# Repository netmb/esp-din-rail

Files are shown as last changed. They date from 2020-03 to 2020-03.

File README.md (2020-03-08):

# esp-din-rail

Din-Rail-Adapter Board for ESP32-Dev-Boards. There are many Dev-Boards available - so please check out if the pin-out matches.
The adapter-board fits in an H-Tronic HUT-6C-casing. Be aware that the current version needs some trimming on the edges, so that it fits exactly into the case.
An upcoming version should fix this issue.

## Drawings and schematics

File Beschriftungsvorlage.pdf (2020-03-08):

18 19 20 21 22 23 24 25 26 27 28 29 30 31 32 33 34 35

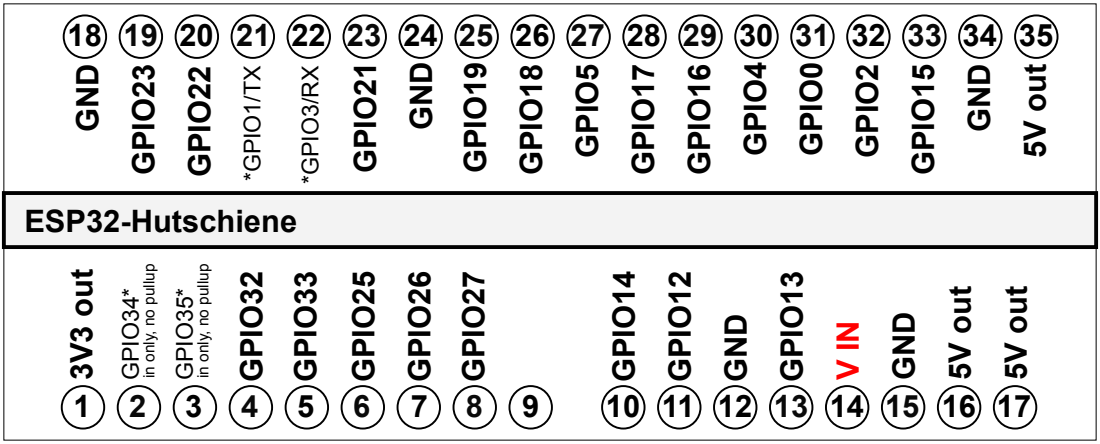
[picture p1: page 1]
10 11 12 13 14 15 16 17 GND GPIO²³ GPIO²² *GPIO¹/TX; *GPIO³/RX; GPIO²¹ GND GPIO¹⁹ GPIO¹⁸ GPIO⁵ GPIO¹⁷ GPIO¹⁶ GPIO⁴ GPIO⁰ GPIO² GPIO¹⁵ GND 5V out 3V³ out; GPIO³⁴* in only, no pullup; GPIO³⁵* in only, no pullup; GPIO³² GPIO³³ GPIO²⁵ GPIO²⁶ GPIO²⁷; GPIO¹⁴ GPIO¹² GND GPIO¹³ V IN GND 5V out; 5V out; ESP32-Hutschiene

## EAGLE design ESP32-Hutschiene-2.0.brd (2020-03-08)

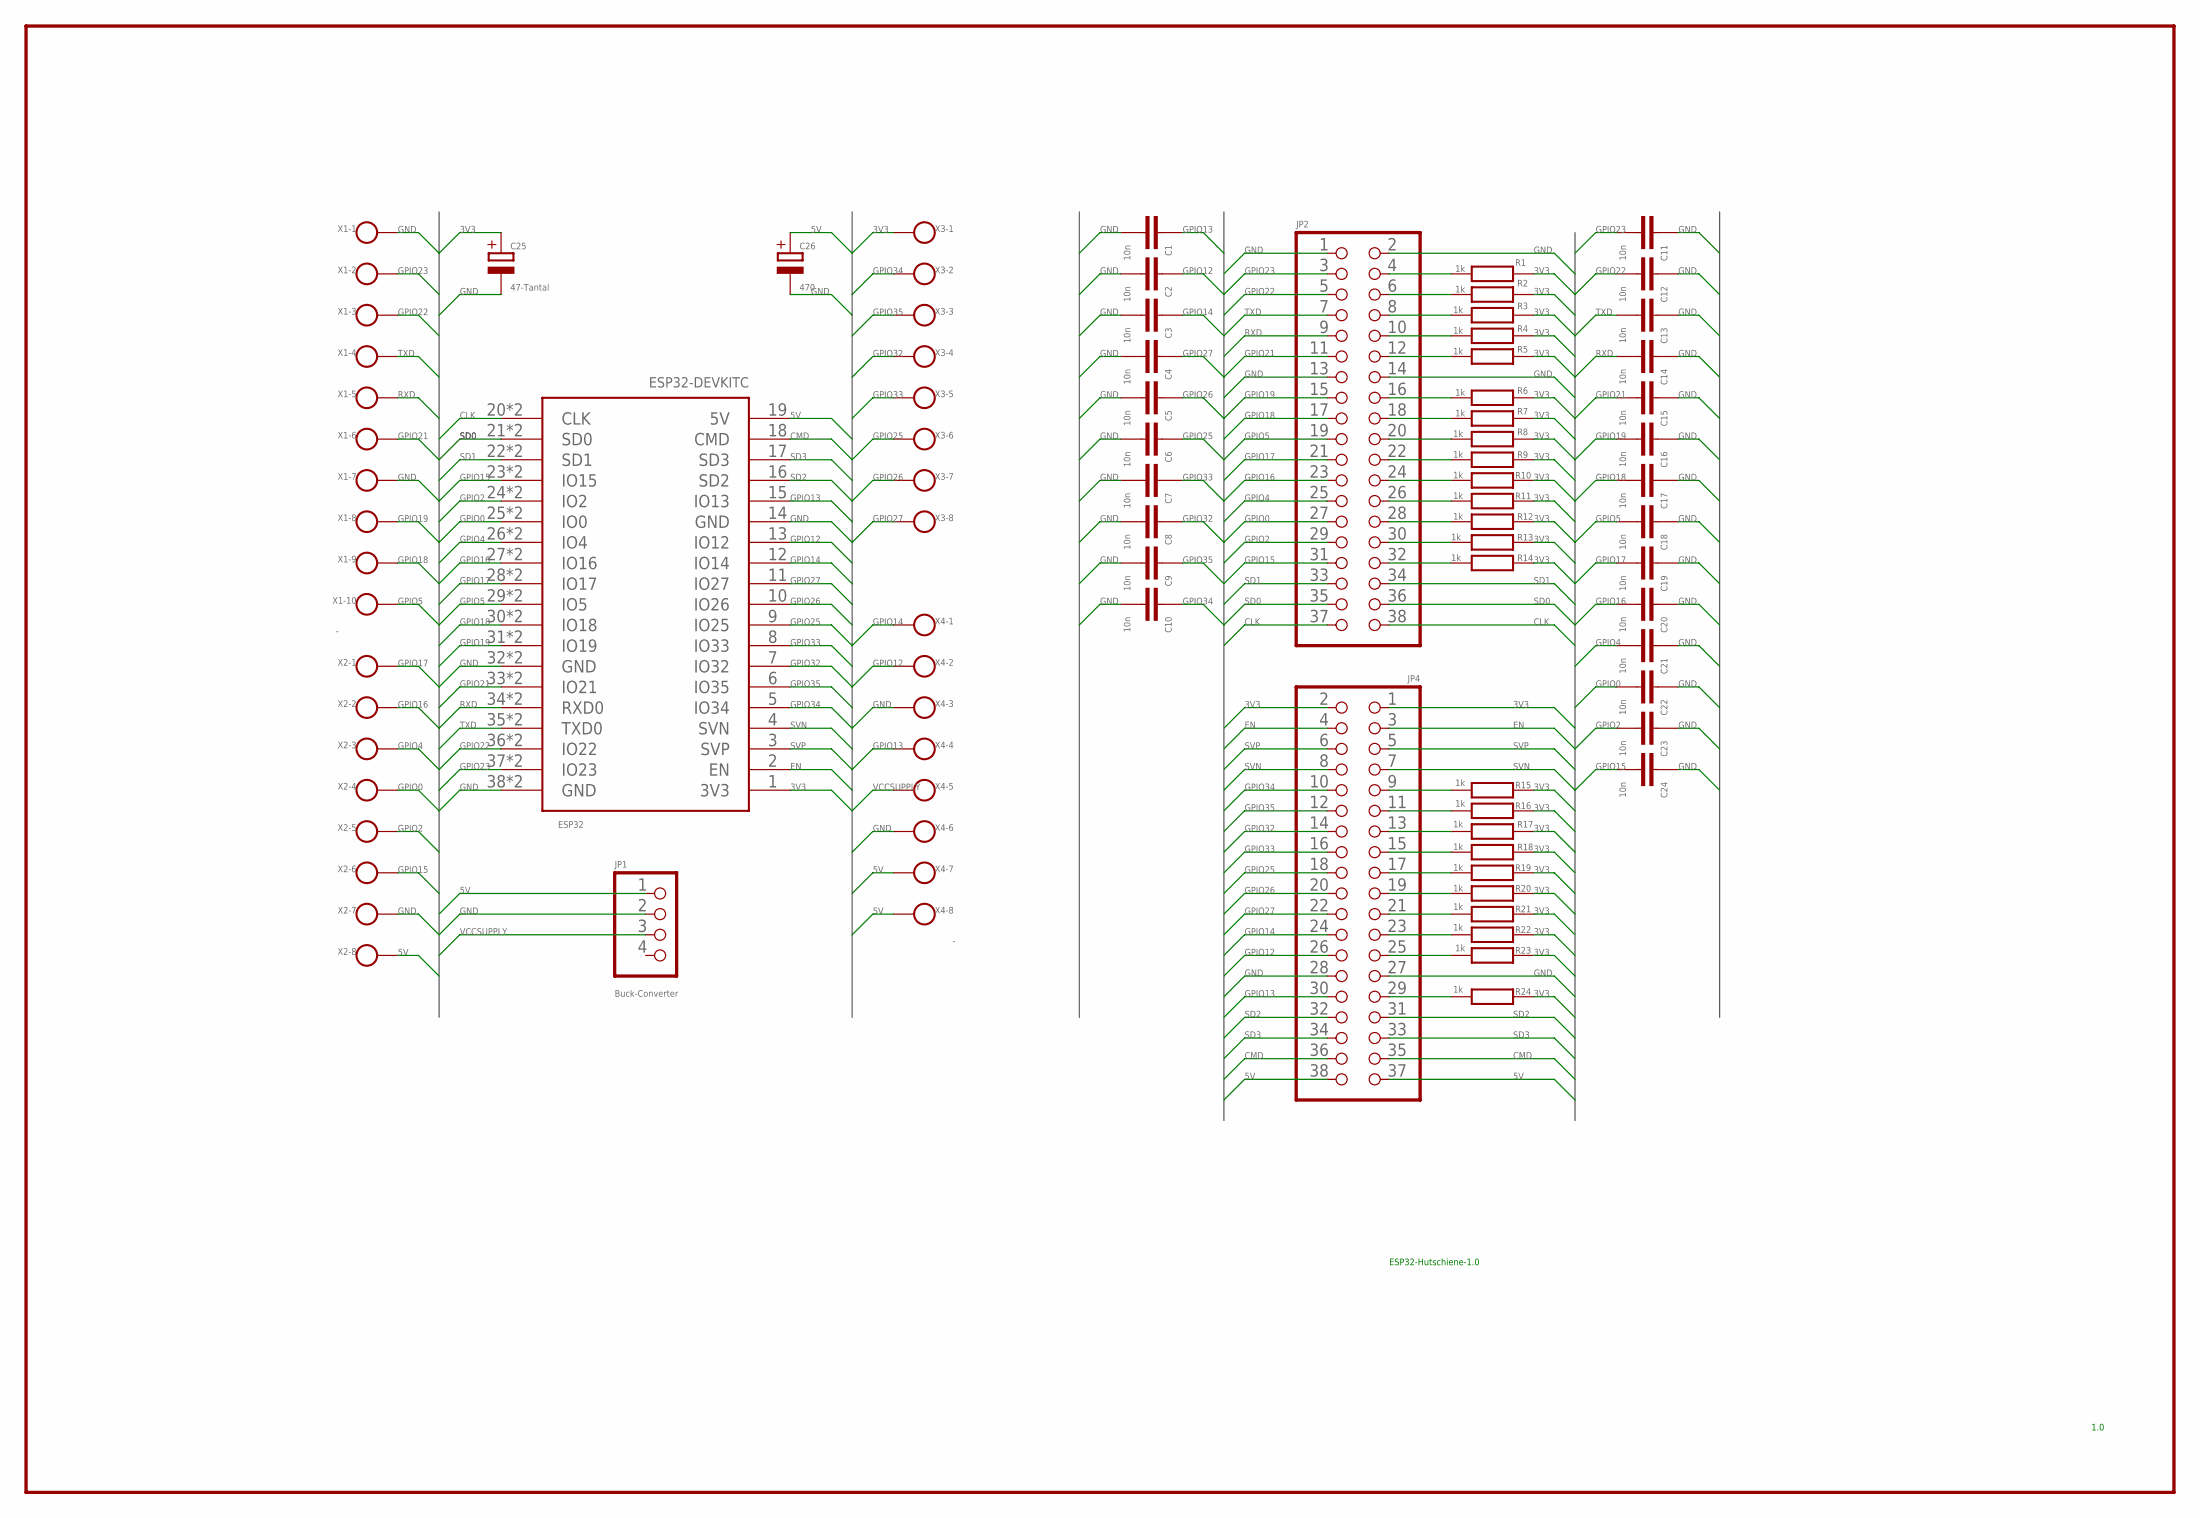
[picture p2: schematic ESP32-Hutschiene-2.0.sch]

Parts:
C1, C2, C3, C4, C5, C6, C7, C8, C9, C10, C11, C12, C13, C14, C15, C16, C17, C18, C19, C20, C21, C22, C23, C24: 10n; C0603
C25: 47-Tantal; E3,5-8
C26: 470; E3,5-8
ESP32: ESP32-DEVKITC-38P
JP1: Buck-Converter; 1X04
JP2, JP4: 2X19
R1, R2, R3, R4, R5, R6, R7, R8, R9, R10, R11, R12, R13, R14, R15, R16, R17, R18, R19, R20, R21, R22, R23, R24: 1k; R0603
X1: -; W237-10P
X2: W237-8P
X3: W237-9P
X4: -; W237-8P

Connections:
3V3: C25.+, ESP32.1 (3V3), JP4.1, JP4.2, R1.2, R2.2, R3.2, R4.2, R5.2, R6.2, R7.2, R8.2, R9.2, R10.2, R11.2, R12.2, R13.2, R14.2, R15.2, R16.2, R17.2, R18.2, R19.2, R20.2, R21.2, R22.2, R23.2, R24.2, X3.1
5V: C26.+, ESP32.19 (5V), JP1.1, JP4.37, JP4.38, X2.8, X4.7, X4.8
CLK: ESP32.20 (CLK), ESP32.57 (CLK), JP2.37, JP2.38
CMD: ESP32.18 (CMD), JP4.35, JP4.36
EN: ESP32.2 (EN), JP4.3, JP4.4
GND: C1.2, C2.2, C3.2, C4.2, C5.2, C6.2, C7.2, C8.2, C9.2, C10.2, C11.1, C12.1, C13.1, C14.1, C15.1, C16.1, C17.1, C18.1, C19.1, C20.1, C21.1, C22.1, C23.1, C24.1, C25.-, C26.-, ESP32.14 (GND), ESP32.32 (GND), ESP32.38 (GND), ESP32.39 (GND), ESP32.45 (GND), JP1.2, JP2.1, JP2.2, JP2.13, JP2.14, JP4.27, JP4.28, X1.1, X1.7, X2.7, X4.3, X4.6
GPIO0: C22.2, ESP32.25 (IO0), ESP32.52 (IO0), JP2.27, X2.4
GPIO2: C23.2, ESP32.24 (IO2), ESP32.53 (IO2), JP2.29, X2.5
GPIO4: C21.2, ESP32.26 (IO4), ESP32.51 (IO4), JP2.25, X2.3
GPIO5: C18.2, ESP32.29 (IO5), ESP32.48 (IO5), JP2.19, X1.10
GPIO12: C2.1, ESP32.13 (IO12), JP4.26, X4.2
GPIO13: C1.1, ESP32.15 (IO13), JP4.30, X4.4
GPIO14: C3.1, ESP32.12 (IO14), JP4.24, X4.1
GPIO15: C24.2, ESP32.23 (IO15), ESP32.54 (IO15), JP2.31, X2.6
GPIO16: C20.2, ESP32.27 (IO16), ESP32.50 (IO16), JP2.23, X2.2
GPIO17: C19.2, ESP32.28 (IO17), ESP32.49 (IO17), JP2.21, X2.1
GPIO18: C17.2, ESP32.30 (IO18), ESP32.47 (IO18), JP2.17, X1.9
GPIO19: C16.2, ESP32.31 (IO19), ESP32.46 (IO19), JP2.15, X1.8
GPIO21: C15.2, ESP32.33 (IO21), ESP32.44 (IO21), JP2.11, X1.6
GPIO22: C12.2, ESP32.36 (IO22), ESP32.41 (IO22), JP2.5, X1.3
GPIO23: C11.2, ESP32.37 (IO23), ESP32.40 (IO23), JP2.3, X1.2
GPIO25: C6.1, ESP32.9 (IO25), JP4.18, X3.6
GPIO26: C5.1, ESP32.10 (IO26), JP4.20, X3.7
GPIO27: C4.1, ESP32.11 (IO27), JP4.22, X3.8
GPIO32: C8.1, ESP32.7 (IO32), JP4.14, X3.4
GPIO33: C7.1, ESP32.8 (IO33), JP4.16, X3.5
GPIO34: C10.1, ESP32.5 (IO34), JP4.10, X3.2
GPIO35: C9.1, ESP32.6 (IO35), JP4.12, X3.3
unnamed: JP2.4, R1.1
unnamed: JP2.6, R2.1
unnamed: JP2.8, R3.1
unnamed: JP2.10, R4.1
unnamed: JP2.12, R5.1
unnamed: JP2.16, R6.1
unnamed: JP2.18, R7.1
unnamed: JP2.20, R8.1
unnamed: JP2.22, R9.1
unnamed: JP2.24, R10.1
unnamed: JP2.26, R11.1
unnamed: JP2.28, R12.1
unnamed: JP2.30, R13.1
unnamed: JP2.32, R14.1
unnamed: JP4.9, R15.1
unnamed: JP4.11, R16.1
unnamed: JP4.13, R17.1
unnamed: JP4.15, R18.1
unnamed: JP4.17, R19.1
unnamed: JP4.19, R20.1
unnamed: JP4.21, R21.1
unnamed: JP4.23, R22.1
unnamed: JP4.25, R23.1
unnamed: JP4.29, R24.1
RXD: C14.2, ESP32.34 (RXD0), ESP32.43 (RXD0), JP2.9, X1.5
SD0: ESP32.21 (SD0), ESP32.56 (SD0), JP2.35, JP2.36
SD1: ESP32.22 (SD1), ESP32.55 (SD1), JP2.33, JP2.34
SD2: ESP32.16 (SD2), JP4.31, JP4.32
SD3: ESP32.17 (SD3), JP4.33, JP4.34
SVN: ESP32.4 (SVN), JP4.7, JP4.8
SVP: ESP32.3 (SVP), JP4.5, JP4.6
TXD: C13.2, ESP32.35 (TXD0), ESP32.42 (TXD0), JP2.7, X1.4
VCCSUPPLY: JP1.3, X4.5

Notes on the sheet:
ESP32-Hutschiene-1.0
1.0

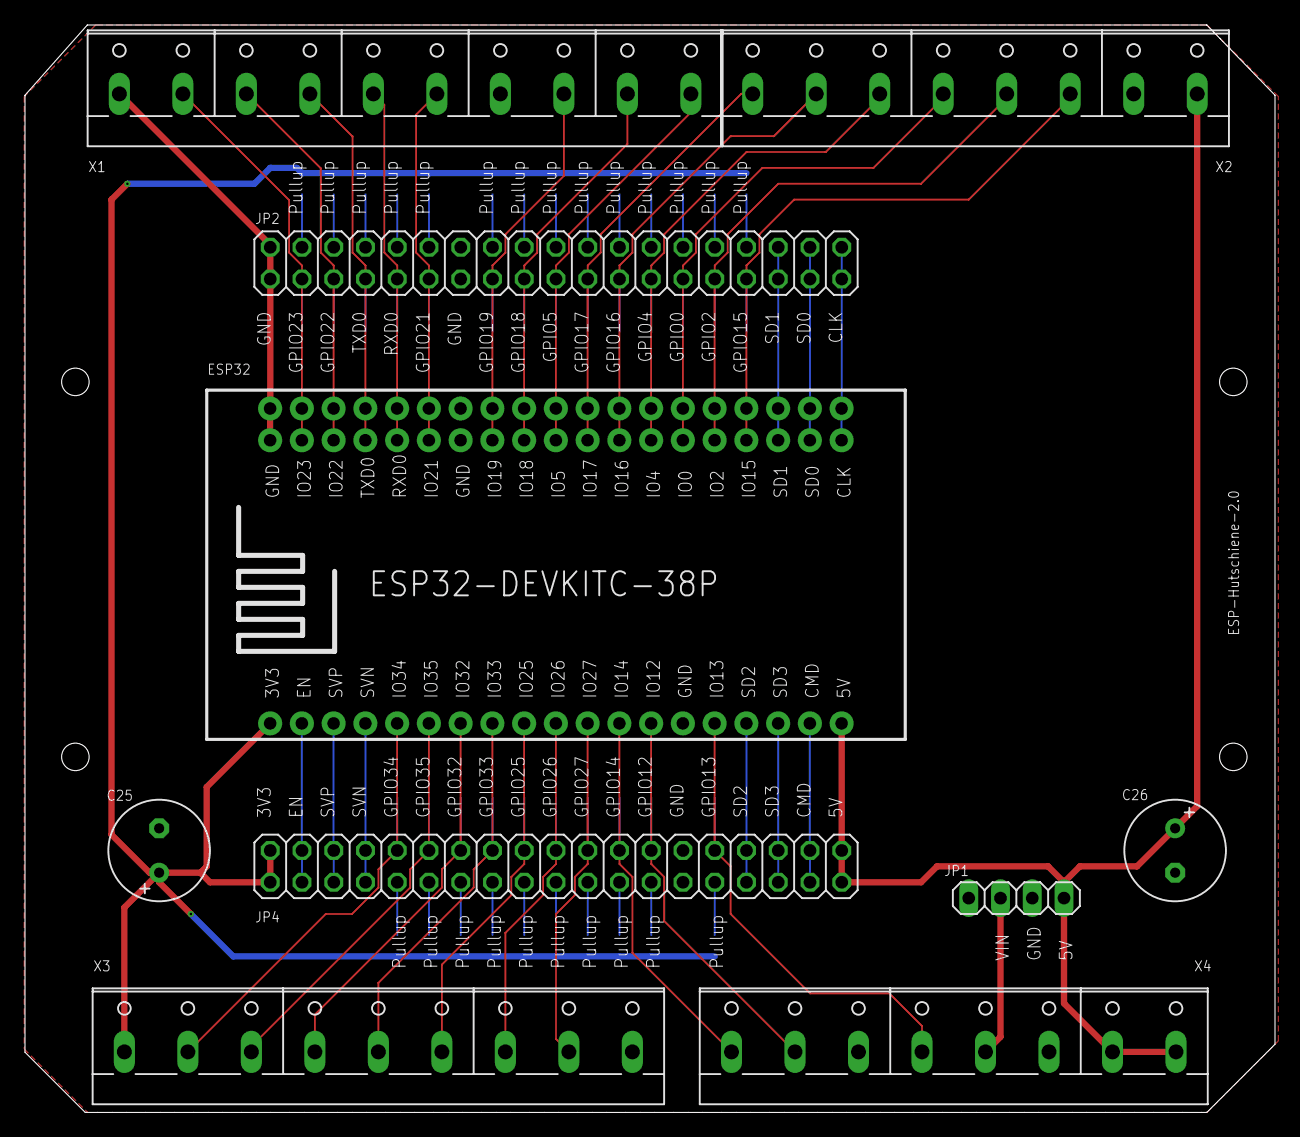
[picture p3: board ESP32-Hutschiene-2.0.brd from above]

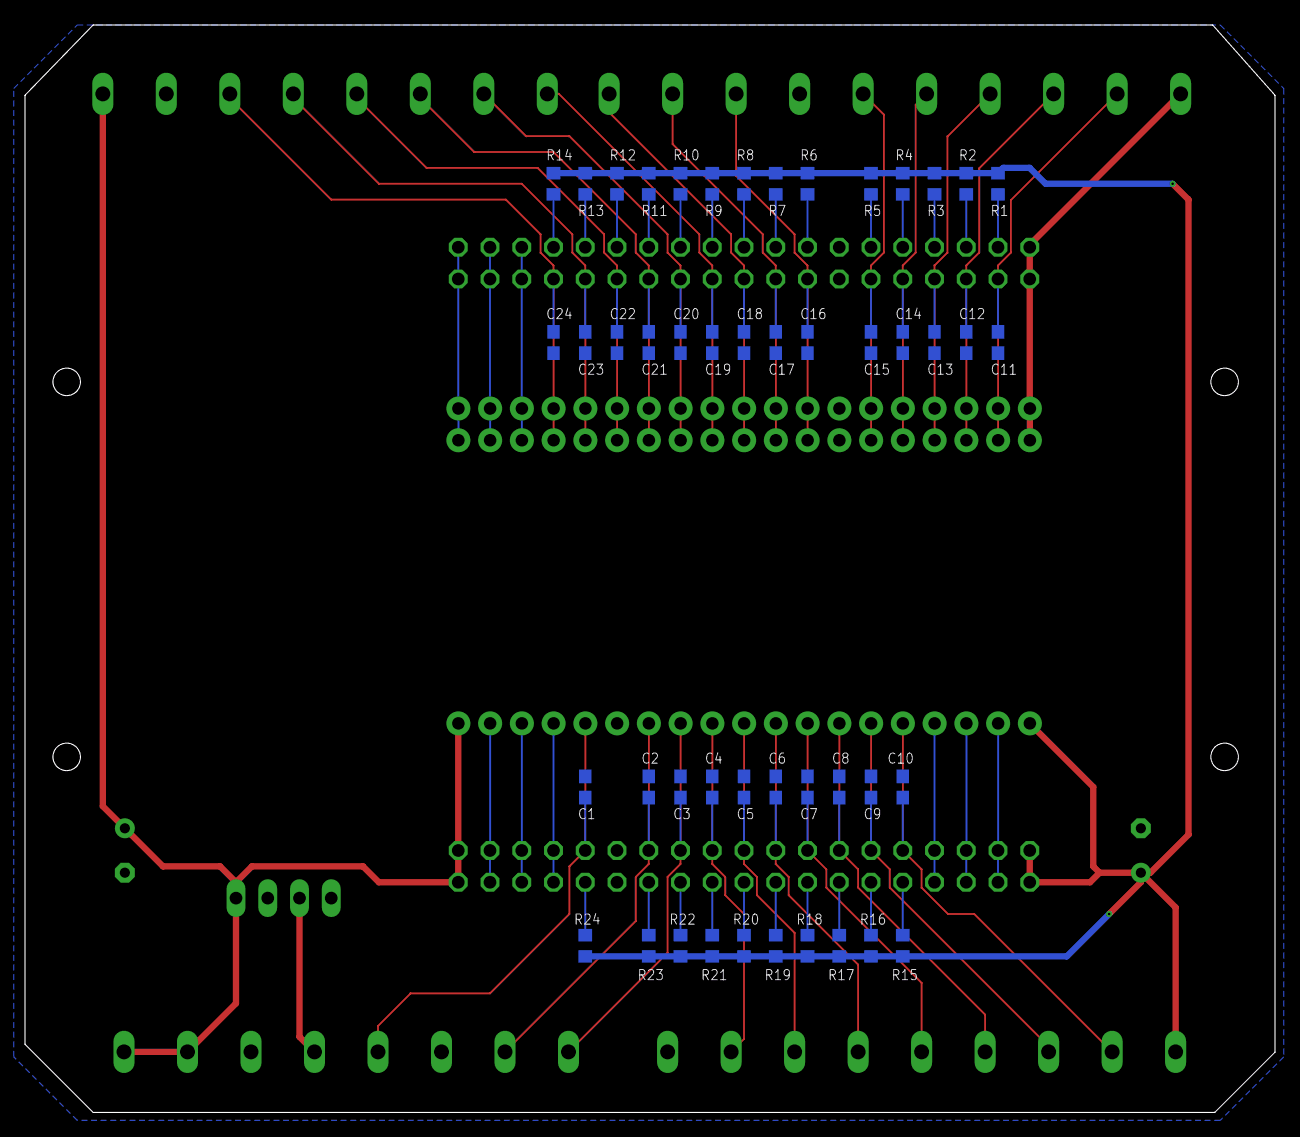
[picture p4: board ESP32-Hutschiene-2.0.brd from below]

Board: 2 copper layers, 100.0 x 87.0 mm, 58 parts (48 on the bottom side), 61 nets.
